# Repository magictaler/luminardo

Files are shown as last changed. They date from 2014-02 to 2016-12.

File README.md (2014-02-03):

Luminardo
=========

An open source Arduino-like hardware project with modular architecture and compact dimentions with the following features in base configuration:

- 8 digits by 6 segments VFD display;
- IR receiver;
- Photocell for brightness adjustmens;
- Buzzer;
- RGB LED with individual colors controlled independently by PWM;
- Single (either 5VDC or 12VDC) power supply;
- Lithium battery bucked up RTC;
- 1 Wire temperature sensor (with capability to connect more than one);
- USB Host functionality*;
- USB-to-Serial interface for progamming and debugging;
- 128 kb of program memory, 3.3V internal supply and logic levels;
- 5V tolerant ISP header; 
- I2C, secondary UART, secondary SPI for future extentions;
- PIR sensor;
- Integration with Arduino IDE;
- Firmware is tightly integrared with an awesome "Revision 2.0 of USB Host Library for Arduino" (thank you guys!)

for more information please visit http://luminardo.net and http://magictale.com

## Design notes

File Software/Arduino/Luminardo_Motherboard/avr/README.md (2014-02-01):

# Luminardo 1284P: Platform files for Luminardo on ATmega1284P

## What is it?

Everything you need to run Luminardo on ATmega1284P.

## Current state

Alpha revision

## Installation

1. Download the [ZIP File](***TBD***)
2. Unzip it a folder called 'hardware'of your sketches directory, e.g. /Users/magictaler/Source/Arduino/hardware/luminardo-1284p
3. Restart the IDE
4. Select Tools > Board > Luminardo 1284p 10MHz
5. To burn the bootloader, follow the Arduino [Bootloader](http://arduino.cc/en/Hacking/Bootloader) instructions.

## Requirements

* Works only on Arduino >= 1.0
* Can be burned using [USBtinyISP](http://www.ladyada.net/make/usbtinyisp/).  That programmer reports errors when flashing to chips with >64k flash size hovewer still does the job.

## See also

http://atmega.magictale.com/Luminardo

## Supported Boards

* 'Luminardo 1284p 10MHz'.  The main and the only board for now.

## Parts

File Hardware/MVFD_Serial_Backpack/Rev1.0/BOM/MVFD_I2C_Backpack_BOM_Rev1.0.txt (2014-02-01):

Partlist exported from D:/Projects/Electronics/InProgress/MVFD_I2C_Backpack/Eagle/Rev1.0/MVFD_I2C_Backpack.sch at 9/28/2013 10:06:53 PM

Qty Value          Device                   Package                   Parts                                      Description                                                             DIGIKEY           LICENSE OPT1 OPT2 OPT3 OPT4   P1     P2  P3   P4  P5 P6 P7 P8 P9  P10 P11 P12   P13  P14  PCBREV              PROJECT              URL                        
3   0.1uF          CAPACITOR_NPOL-1206      C1206                     C1, C2, C3                                 Non-Polarized capacitor in various packages                             445-14296-1-ND                                                                                                                                                                  
1   100K           RESISTOR-1206            R1206                     R4                                                                                                                 RHM100KYCT-ND                                                                                                                                                                   
1   10K            RESISTOR-1206            R1206                     R1                                                                                                                 RHM10KZCT-ND                                                                                                                                                                    
1   10uF           CAPACITOR_NPOL-1206      C1206                     C6                                         Non-Polarized capacitor in various packages                             399-1299-1-ND                                                                                                                                                                   
1   16MHz          OSC-XTAL-HC-49U-SMD      HC-49U                    Y1                                                                                                                 887-1059-1-ND                                                                                                                                                                   
2   1K5            RESISTOR-1206            R1206                     R2, R3                                                                                                             RHM1.50KYCT-ND                                                                                                                                                                  
2   22pF           CAPACITOR_NPOL-1206      C1206                     C4, C5                                     Non-Polarized capacitor in various packages                             399-8165-1-ND                                                                                                                                                                   
1   ATMEGA328P     ATMEGA168                TQFP32-08                 U1                                                                                                                 ATMEGA328P-AU-ND                                                                                                                                                                
1   CTRL           CONN_HEADER_2X07F_MIRR   CONN_HEADER_2X07_F_MIRR   P4                                         JUMPER                                                                  S7075-ND                                                                                                                                                                        
1   DMG2307L-7     TRANSISTOR_FET_TSM2301CX SOT-23                    Q1                                         20V P-Channel Enhancement Mode MOSFET                                   DMG2307L-7DICT-ND                                                                                                                                                               
4   FIDUCIAL       FIDUCIAL                 FIDUCIAL_1MM              FIDUTIAL1, FIDUTIAL2, FIDUTIAL3, FIDUTIAL4 For use by pick and place machines to calibrate the vision/machine, 1mm                                                                                                                                                                                 
1   HDR_7P2R_DESCR HDR_7P2R_DESCR           HDR_7P2R_DESCR            U$2                                                                                                                                                                IR_REC +5V SPKR GND DO B  DI G  CLK R   CS  L_SNR VSEG SHDN                                                                     
1   I2C            CONN_HEADER_1X04RA_POLAR CONN_HEADER_1X04_RA_POLAR P1                                         2.54 1x4 Header                                                         732-2701-ND                                                                                                                                                                     
1   ISP            CONN_HEADER_2X03         CONN_HEADER_2X03          P3                                         2.54 2x3 Header                                                         3M9459-ND                                                                                                                                                                       
1   JUMP_4X2_DESCR JUMP_4X2_DESCR           JUMP_4X2_DESCR            U$4                                                                                                                                          A1   A2   A3   SER_EN                                                                                                                                 
2   MOUNT-HOLE3.3  MOUNT-HOLE3.3            3,3                       H1, H2                                     MOUNTING HOLE with drill center marker                                                                                                                                                                                                                  
1   MT_LOGO        MT_LOGO                  MT_LOGO                   U$1                                                                                                                                  CC3.0                                                                                     REV 1.0, 2013.09.28 MVFD Serial Backpack http://atmega.magictale.com
1   OPT SEL        CONN_HEADER_2X04         CONN_HEADER_2X04          JP1                                        2.54 2x4 Header                                                         609-3226-ND                                                                                                                                                                     
1   SERIAL         CONN_HEADER_1X04RA_POLAR CONN_HEADER_1X04_RA_POLAR P2                                         2.54 1x4 Header                                                         732-2701-ND

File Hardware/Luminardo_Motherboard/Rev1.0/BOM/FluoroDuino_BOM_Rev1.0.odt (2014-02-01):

FluoroDuino Rev.1.0

Bill Of Materials

Picture | Position | DIGIKEY Part Number | Value | Unit price, USD | Qty | Extended price, USD
| B1 | BS-3-ND | HOLDER COINCELL 2032 RETAINR ARM | 0.79 | 1 | 0.79
| C1, C2, C4, C6, C11, C12, C13, C14, C15, C16, C21 | 445-14296-1-ND | CAP CER 0.1UF 50V 20% X5R 0612 | 0.38 | 11 | 4.16
| C10, C22 | 276-3044-1-ND | CAP CER 10UF 10V 20% X5R 1206 | 0.23 | 2 | 0.46
| C17 | 399-1234-1-ND | CAP CER 10000PF 50V 10% X7R 1206 | 0.16 | 1 | 0.16
| C18 | P16502CT-ND | CAP ALUM 56UF 20V 20% SMD | 1.28 | 1 | 1.28
| C20 | 587-1434-1-ND | CAP CER 1UF 25V 10% X5R 1206 | 0.48 | 1 | 0.48
| C3, C5, C8, C9 | 1276-1844-1-ND | CAP CER 18PF 50V 5% NP0 1206 | 0.16 | 4 | 0.64
| C7, C19 | 445-14685-1-ND | CAP CER 4.7UF 25V 20% X5R 1206 | 0.35 | 2 | 0.7
| D1, D2 | 568-6504-1-ND | DIODE SCHOTTKY 20V 1A SOD123W | 0.48 | 2 | 0.96
| F1 | 507-1798-1-ND | PTC RESTTBLE 0.25A 16V CHIP 1206 | 0.12 | 1 | 0.12
| J1 | CP-012A-ND | CONN PWR JCK 2.0 X 6.6MM | 1.4 | 1 | 1.4
| L1 | 445-6533-1-ND | INDUCTOR POWER 22UH 1.7A SMD | 0.52 | 1 | 0.52
| LD1, LD2 | 160-1737-1-ND | LED WHITE YELLOW 260MCD 1206 | 0.58 | 1 | 1.16
| P1 | 1175-1265-ND | USB 2.0 A/FEMALE DIP 180 DEG | 0.83 | 1 | 0.83
| P11 | SAM1034-01-ND | CONN HEADER 2POS .100" DUAL TIN | 0.85 | 1 | 0.85
| P2, P4 | SAM1034-02-ND | CONN HEADER 4POS .100" DUAL TIN | 1.86 | 1 | 1.86
| P3, P10 | SAM1034-02-ND | CONN HEADER 4POS .100" DUAL TIN | 1.86 | 1 | 1.86
| P5 | 732-2735-ND | CONN MINI USB 5PIN VERT T/H | 3.18 | 1 | 3.18
| P6, P9 | 609-3210-ND | CONN HEADER 6POS .100 STR 15AU | 0.58 | 1 | 0.58
| P7 | 609-3235-ND | CONN HEADER 8POS .100 STR 15AU | 0.32 | 1 | 0.32
| P8 | OR1103-ND | JUMPER PLUG 14POS DOUBLE ROW | 0.76 | 1 | 0.76
| Q1 | DMG2307L-7DICT-ND | MOSFET P-CH 30V 2.5A SOT-23 | 0.44 | 1 | 0.44
| R1, R2, R3, R8, R15 | RMCF1206JT10K0CT-ND | RES 10K OHM 1/4W 5% 1206 | 0.05 | 5 | 0.25
| R10, R11, R12, R13 | RMCF1206JT1K00CT-ND | RES 1K OHM 1/4W 5% 1206 | 0.05 | 4 | 0.2
| R14 | RMCF1206JT100KCT-ND | RES 100K OHM 1/4W 5% 1206 | 0.05 | 1 | 0.05
| R4, R5 | RMCF1206JT33R0 | RES 33 OHM 1/4W 5% 1206 | 0.05 | 2 | 0.1
| R6 | RMCF1206JT4K70CT-ND | RES 4.7K OHM 1/4W 5% 1206 | 0.05 | 1 | 0.05
| R7, R9 | RNCP1206FTD1K50CT-ND | RES 1.5K OHM 1/2W 1% 1206 | 0.09 | 2 | 0.18
| U1 | DS18B20+T&RCT-ND | IC THERM MICROLAN PROG-RES TO92 | 4.6 | 1 | 4.6
| U2 | MAX3421EEHJ+-ND | IC USB PERIPH/HOST CNTRL 32TQFP | 13.21 | 1 | 13.21
| U3 | ATMEGA1284P-AURCT-ND | IC MCU 8BIT 128KB FLASH 44TQFP | 8.43 | 1 | 8.43
| U4 | NCP380HSN05AAT1GOSCT-ND | IC CURRENT LIMIT SWITCH 5-TSOP | 0.74 | 1 | 0.74
| U5 | 296-4530-1-ND | IC BUS BUFFER TRI-ST QD 14SOICN | 0.49 | 1 | 0.49
| U6 | 768-1007-1-ND | IC USB FS SERIAL UART 28-SSOP | 4.5 | 1 | 4.5
| U7 | DS1338U-33+T&RCT-ND | IC RTC 56BYTE NV RAM 3.3V 8-USOP | 3.28 | 1 | 3.28
| U8 | LM22675MR-5.0/NOPB-ND | LM22675MR-5.0/NOPB-ND | 3.91 | 1 | 3.91
| U9 | 497-1241-1-ND | IC REG LDO 3.3V 0.95A SOT223 | 0.54 | 1 | 0.54
| Y1 | 535-9833-1-ND | CRYSTAL 10MHZ 18PF SMD | 1.31 | 1 | 1.31
| Y2 | 535-9836-1-ND | CRYSTAL 12MHZ 18PF SMD | 1.31 | 1 | 1.31
| Y3 | 300-8816-1-ND | CRYSTAL 32.768KHZ 12.5PF SMD | 1.43 | 1 | 1.43
| ZD1 | 1N5819HW-FDICT-ND | DIODE SCHOTTKY 40V 1A SOD123 | 0.52 | 1 | 0.52
Total | | | | | | 68.61

Rev.1.0 http://magictale.com 4 Of 6

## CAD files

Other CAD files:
Hardware/MVFD_Serial_Backpack/Rev1.0/Sketchup/MVFD_16S8D_Serial_Backpack_3D_Rev1.0.skp

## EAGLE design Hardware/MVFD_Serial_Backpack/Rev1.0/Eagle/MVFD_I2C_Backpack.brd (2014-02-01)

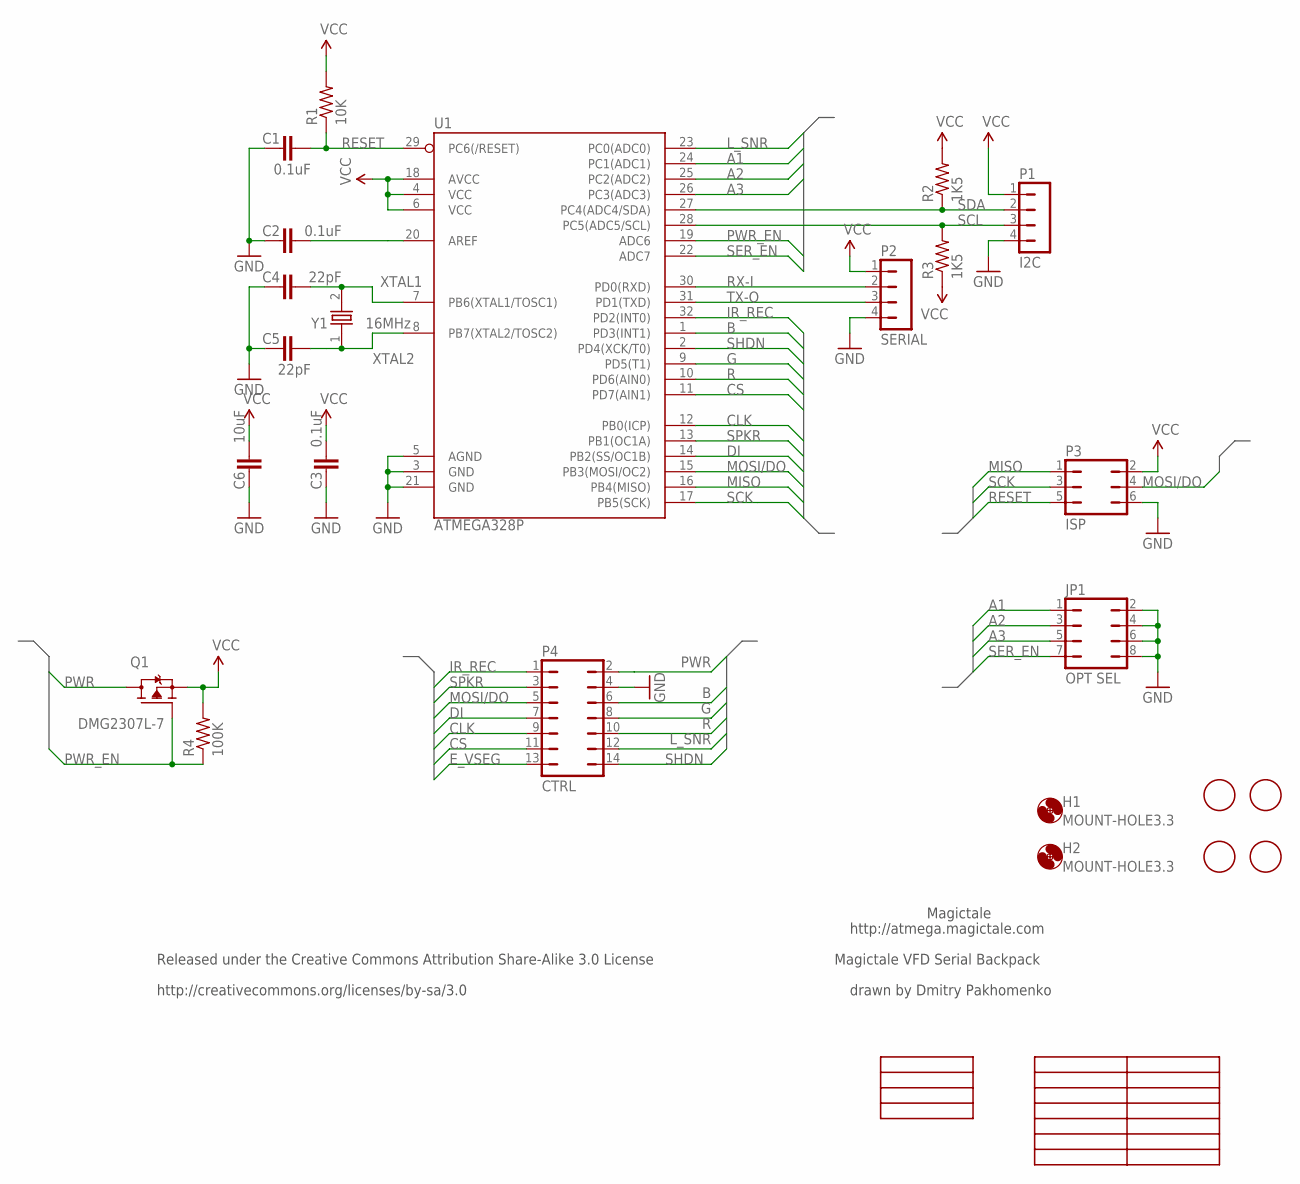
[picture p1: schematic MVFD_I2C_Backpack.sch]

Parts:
C1, C2, C3: 0.1uF; C1206; DIGIKEY 445-14296-1-ND
C4, C5: 22pF; C1206; DIGIKEY 399-8165-1-ND
C6: 10uF; C1206; DIGIKEY 399-1299-1-ND
FIDUTIAL1, FIDUTIAL2, FIDUTIAL3, FIDUTIAL4: FIDUCIAL; FIDUCIAL_1MM
H1, H2: MOUNT-HOLE3.3; 3,3
JP1: OPT SEL; CONN_HEADER_2X04; DIGIKEY 609-3226-ND
P1: I2C; CONN_HEADER_1X04_RA_POLAR; DIGIKEY 732-2701-ND
P2: SERIAL; CONN_HEADER_1X04_RA_POLAR; DIGIKEY 732-2701-ND
P3: ISP; CONN_HEADER_2X03; DIGIKEY 3M9459-ND
P4: CTRL; CONN_HEADER_2X07_F_MIRR; DIGIKEY S7075-ND
Q1: DMG2307L-7; SOT-23; DIGIKEY DMG2307L-7DICT-ND
R1: 10K; R1206; DIGIKEY RHM10KZCT-ND
R2, R3: 1K5; R1206; DIGIKEY RHM1.50KYCT-ND
R4: 100K; R1206; DIGIKEY RHM100KYCT-ND
U1: ATMEGA328P; TQFP32-08; DIGIKEY ATMEGA328P-AU-ND
U$1: MT_LOGO
U$2: HDR_7P2R_DESCR
U$4: JUMP_4X2_DESCR
Y1: 16MHz; HC-49U; DIGIKEY 887-1059-1-ND

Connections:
A1: JP1.1, U1.24 (PC1(ADC1))
A2: JP1.3, U1.25 (PC2(ADC2))
A3: JP1.5, U1.26 (PC3(ADC3))
AREF: C2.2, U1.20 (AREF)
B: P4.6, U1.1 (PD3(INT1))
CLK: P4.9, U1.12 (PB0(ICP))
CS: P4.11, U1.11 (PD7(AIN1))
DI: P4.7, U1.14 (PB2(SS/OC1B))
E_VSEG: P4.13
G: P4.8, U1.9 (PD5(T1))
GND: C1.1, C2.1, C3.1, C4.1, C5.1, C6.1, JP1.2, JP1.4, JP1.6, JP1.8, P1.4, P2.4, P3.6, P4.4, U1.3 (GND), U1.5 (AGND), U1.21 (GND)
IR_REC: P4.1, U1.32 (PD2(INT0))
L_SNR: P4.12, U1.23 (PC0(ADC0))
MISO: P3.1, U1.16 (PB4(MISO))
MOSI/DO: P3.4, P4.5, U1.15 (PB3(MOSI/OC2))
PWR: P4.2, Q1.3 (D)
PWR_EN: Q1.1 (G), R4.1, U1.19 (ADC6)
R: P4.10, U1.10 (PD6(AIN0))
RESET: C1.2, P3.5, R1.1, U1.29 (PC6(/RESET))
RX-I: P2.2, U1.30 (PD0(RXD))
SCK: P3.3, U1.17 (PB5(SCK))
SCL: P1.3, R3.2, U1.28 (PC5(ADC5/SCL))
SDA: P1.2, R2.1, U1.27 (PC4(ADC4/SDA))
SER_EN: JP1.7, U1.22 (ADC7)
SHDN: P4.14, U1.2 (PD4(XCK/T0))
SPKR: P4.3, U1.13 (PB1(OC1A))
TX-O: P2.3, U1.31 (PD1(TXD))
VCC: C3.2, C6.2, P1.1, P2.1, P3.2, Q1.2 (S), R1.2, R2.2, R3.1, R4.2, U1.4 (VCC), U1.6 (VCC), U1.18 (AVCC)
XTAL1: C4.2, U1.7 (PB6(XTAL1/TOSC1)), Y1.2
XTAL2: C5.2, U1.8 (PB7(XTAL2/TOSC2)), Y1.1

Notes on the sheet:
Magictale
http://atmega.magictale.com
Magictale VFD Serial Backpack
drawn by Dmitry Pakhomenko
Released under the Creative Commons Attribution Share-Alike 3.0 License
http://creativecommons.org/licenses/by-sa/3.0

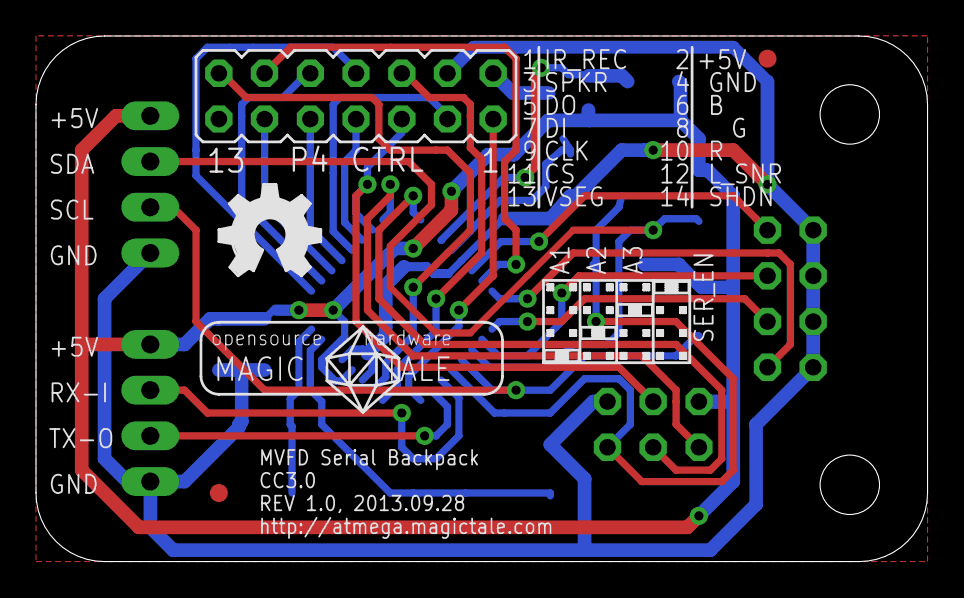
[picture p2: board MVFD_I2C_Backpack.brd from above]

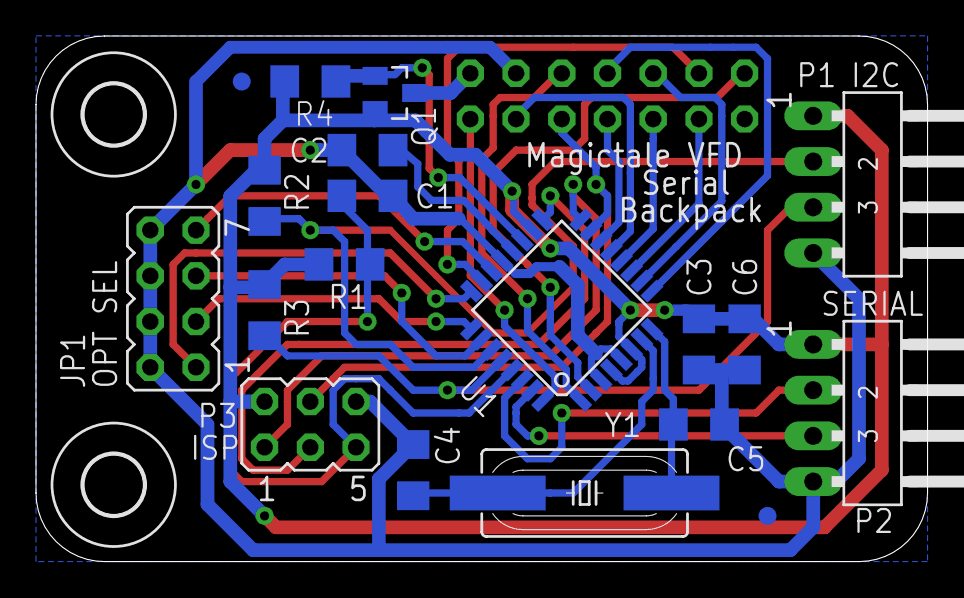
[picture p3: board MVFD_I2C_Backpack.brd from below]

Board: 2 copper layers, 49.5 x 29.2 mm, 28 parts (22 on the bottom side), 29 nets.

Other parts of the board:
U$3: LOGO_OSHW_FILLX200_NOTEXT

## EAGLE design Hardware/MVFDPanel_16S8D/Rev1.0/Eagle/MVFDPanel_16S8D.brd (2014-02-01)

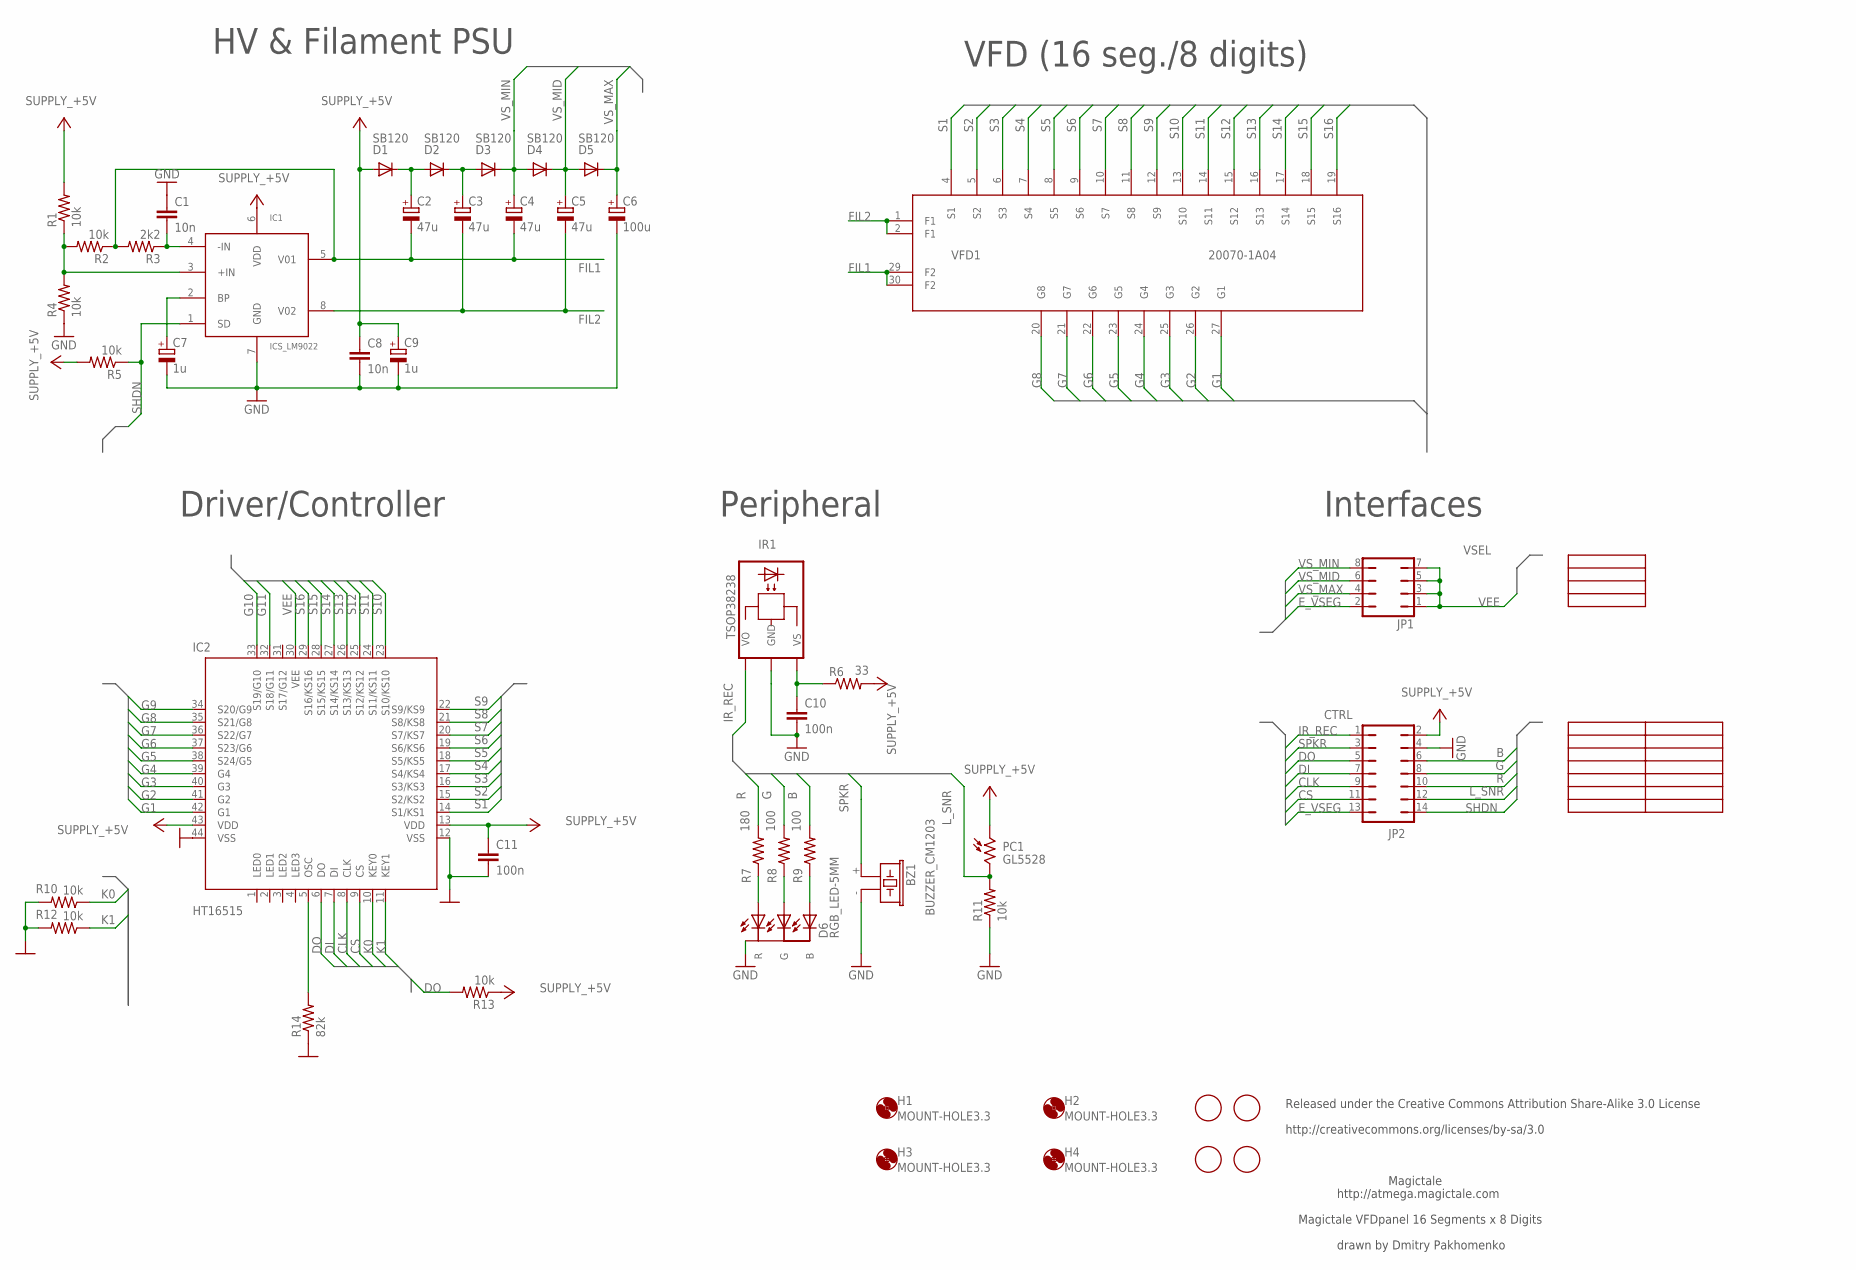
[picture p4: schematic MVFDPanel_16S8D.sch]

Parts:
BZ1: BUZZER_CM1203; CEM-1203
C1, C8: 10n; C025-025X050; DIGIKEY 399-4150-ND
C2, C3, C4, C5: 47u; E2,5-7; DIGIKEY P11232-ND
C6: 100u; E3,5-8; DIGIKEY P10294-ND
C7, C9: 1u; E2-5; DIGIKEY P13468-ND
C10, C11: 100n; C050-025X075; DIGIKEY 490-3859-ND
D1, D2, D3, D4, D5: SB120; DO41-10; DIGIKEY MBR160-ND
D6: RGB_LED-5MM
FIDUTIAL1, FIDUTIAL2, FIDUTIAL3, FIDUTIAL4: FIDUCIAL; FIDUCIAL_1MM
H1, H2, H3, H4: MOUNT-HOLE3.3; 3,3
IC1: ICS_LM9022; ICS_SOP08; DIGIKEY LM9022M-ND
IC2: HT16515; LQFP44-10X10
IR1: TSOP38238; DIGIKEY 751-1227-ND
JP1: VSEL; JP4Q
JP2: CTRL; JP7Q
PC1: GL5528
R1, R2, R4, R5, R10, R11, R12, R13: 10k; 0207/2V; DIGIKEY 10KQBK-ND
R3: 2k2; 0207/2V; DIGIKEY 2.2KQTR-ND
R6: 33; 0207/2V; DIGIKEY 33QBK-ND
R7: 180; 0207/2V; DIGIKEY 180QBK-ND
R8, R9: 100; 0207/2V; DIGIKEY 100QBK-ND
R14: 82k; 0207/2V; DIGIKEY 82KQBK-ND
U$1: MT_LOGO
U$2: HDR_7P2R_DESCR
U$3: JUMP_4X2_DESCR
VFD1: 20070-1A04

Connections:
+5V: C8.1, C9.+, C11.1, D1.A, IC1.6 (VDD), IC2.13 (VDD), IC2.43 (VDD), JP2.2, PC1.1, R1.2, R5.2, R6.2, R13.1
B: JP2.6, R9.2
CLK: IC2.8 (CLK), JP2.9
CS: IC2.9 (CS), JP2.11
DI: IC2.7 (DI), JP2.7
DO: IC2.6 (DO), JP2.5, R13.2
E_VSEG: JP1.2, JP2.13
FIL1: C2.-, C4.-, IC1.5 (V01), R2.1, R3.2, VFD1.29 (F2), VFD1.30 (F2)
FIL2: C3.-, C5.-, IC1.8 (V02), VFD1.1 (F1), VFD1.2 (F1)
G: JP2.8, R8.2
G1: IC2.42 (G1), VFD1.27 (G1)
G2: IC2.41 (G2), VFD1.26 (G2)
G3: IC2.40 (G3), VFD1.25 (G3)
G4: IC2.39 (G4), VFD1.24 (G4)
G5: IC2.38 (S24/G5), VFD1.23 (G5)
G6: IC2.37 (S23/G6), VFD1.22 (G6)
G7: IC2.36 (S22/G7), VFD1.21 (G7)
G8: IC2.35 (S21/G8), VFD1.20 (G8)
G9: IC2.34 (S20/G9)
G10: IC2.33 (S19/G10)
G11: IC2.32 (S18/G11)
GND: BZ1.- (2), C1.1, C6.-, C7.-, C8.2, C9.-, C10.2, C11.2, D6.CC, IC1.7 (GND), IC2.12 (VSS), IC2.44 (VSS), IR1.GND, JP2.4, R4.1, R10.2, R11.1, R12.2, R14.1
IR_REC: IR1.VO, JP2.1
K0: IC2.10 (KEY0), R10.1
K1: IC2.11 (KEY1), R12.1
L_SNR: JP2.12, PC1.2, R11.2
unnamed: C10.1, IR1.VS, R6.1
unnamed: IC2.5 (OSC), R14.2
unnamed: C7.+, IC1.2 (BP)
unnamed: D6.R, R7.1
unnamed: D6.G, R8.1
unnamed: D6.B, R9.1
unnamed: IC1.3 (+IN), R1.1, R2.2, R4.2
unnamed: C2.+, D1.C, D2.A
unnamed: C3.+, D2.C, D3.A
PORTD6: C1.2, IC1.4 (-IN), R3.1
R: JP2.10, R7.2
S1: IC2.14 (S1/KS1), VFD1.4 (S1)
S2: IC2.15 (S2/KS2), VFD1.5 (S2)
S3: IC2.16 (S3/KS3), VFD1.6 (S3)
S4: IC2.17 (S4/KS4), VFD1.7 (S4)
S5: IC2.18 (S5/KS5), VFD1.8 (S5)
S6: IC2.19 (S6/KS6), VFD1.9 (S6)
S7: IC2.20 (S7/KS7), VFD1.10 (S7)
S8: IC2.21 (S8/KS8), VFD1.11 (S8)
S9: IC2.22 (S9/KS9), VFD1.12 (S9)
S10: IC2.23 (S10/KS10), VFD1.13 (S10)
S11: IC2.24 (S11/KS11), VFD1.14 (S11)
S12: IC2.25 (S12/KS12), VFD1.15 (S12)
S13: IC2.26 (S13/KS13), VFD1.16 (S13)
S14: IC2.27 (S14/KS14), VFD1.17 (S14)
S15: IC2.28 (S15/KS15), VFD1.18 (S15)
S16: IC2.29 (S16/KS16), VFD1.19 (S16)
SHDN: IC1.1 (SD), JP2.14, R5.1
SPKR: BZ1.+ (1), JP2.3
VEE: IC2.30 (VEE), JP1.1, JP1.3, JP1.5, JP1.7
VS_MAX: C6.+, D5.C, JP1.4
VS_MID: C5.+, D4.C, D5.A, JP1.6
VS_MIN: C4.+, D3.C, D4.A, JP1.8

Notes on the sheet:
HV & Filament PSU
Driver/Controller
VFD (16 seg./8 digits)
Peripheral
Interfaces
Magictale
http://atmega.magictale.com
Magictale VFDpanel 16 Segments x 8 Digits
drawn by Dmitry Pakhomenko
Released under the Creative Commons Attribution Share-Alike 3.0 License
http://creativecommons.org/licenses/by-sa/3.0

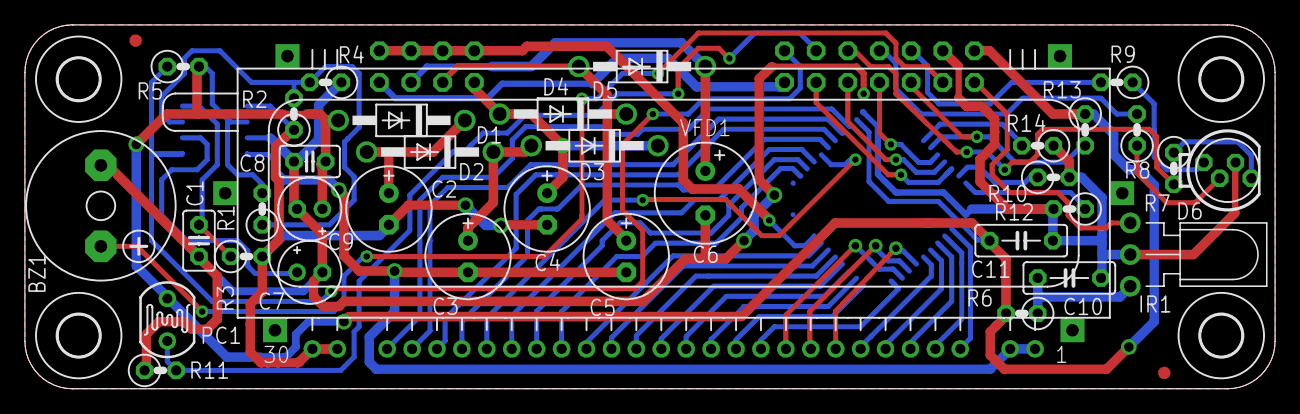
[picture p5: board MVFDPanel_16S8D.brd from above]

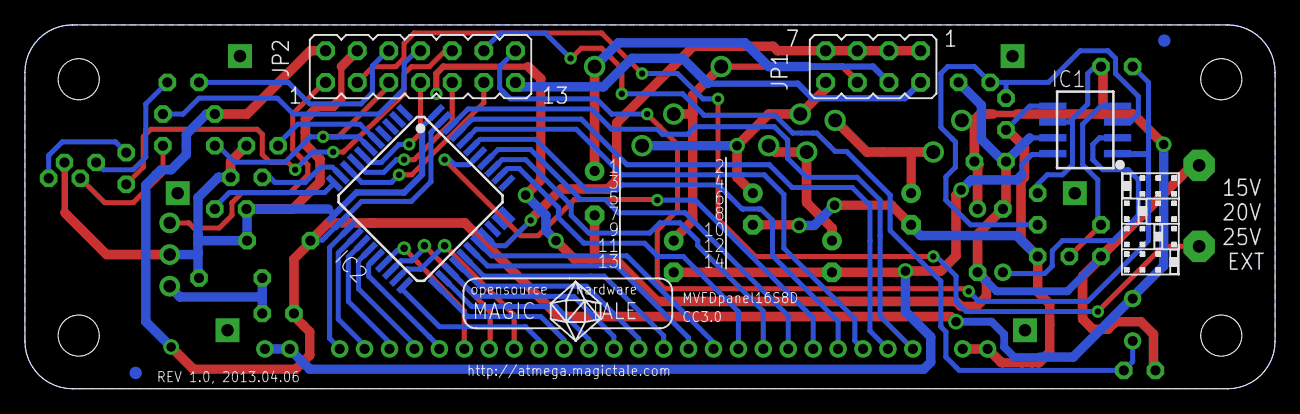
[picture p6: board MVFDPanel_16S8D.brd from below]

Board: 2 copper layers, 100.3 x 29.2 mm, 50 parts (9 on the bottom side), 56 nets.

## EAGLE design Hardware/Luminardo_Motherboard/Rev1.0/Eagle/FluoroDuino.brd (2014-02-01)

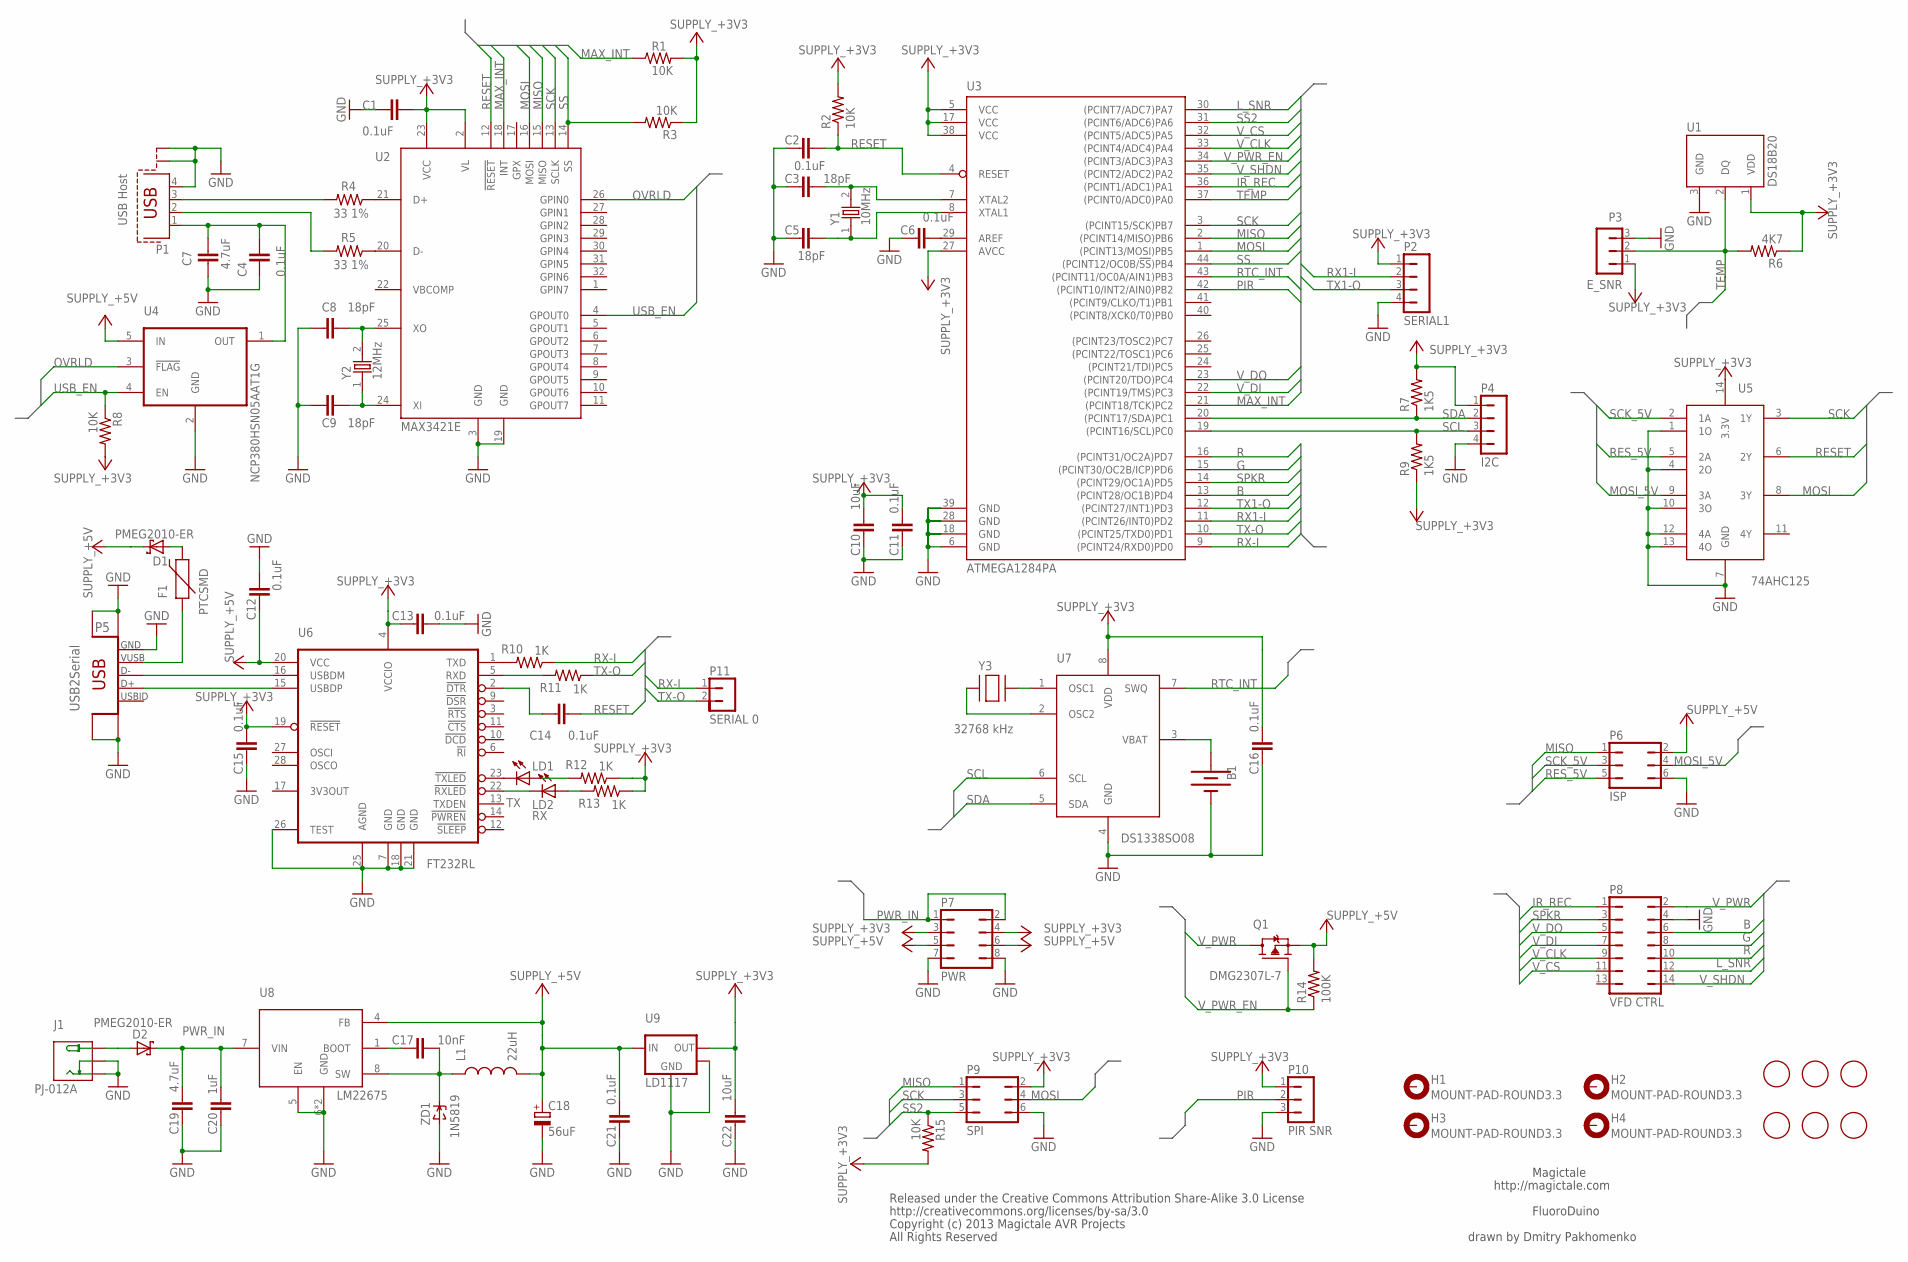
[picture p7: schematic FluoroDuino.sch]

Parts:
B1: BATTERY20PTH; BATTCOM_20MM_PTH; DIGIKEY BS-3-ND
C1, C2, C4, C6, C11, C12, C13, C14, C15, C16, C21: 0.1uF; C1206; DIGIKEY 445-14296-1-ND
C3, C5, C8, C9: 18pF; C1206; DIGIKEY 1276-1844-1-ND
C7, C19: 4.7uF; C1206; DIGIKEY 445-14685-1-ND
C10: 10uF; C1206; DIGIKEY 276-3044-1-ND
C17: 10nF; C1206; DIGIKEY 399-1234-1-ND
C18: 56uF; PANASONIC_C; DIGIKEY P16502CT-ND
C20: 1uF; C1206; DIGIKEY 587-1434-1-ND
C22: 10uF; C1206; DIGIKEY 1276-3044-1-ND
D1, D2: PMEG2010-ER; SOD123; DIGIKEY 568-6504-1-ND
F1: PTCSMD; PTC-1206; DIGIKEY 507-1798-1-ND
FIDUTIAL1, FIDUTIAL2, FIDUTIAL3, FIDUTIAL4, FIDUTIAL5, FIDUTIAL6: FIDUCIAL; FIDUCIAL_1MM
H1, H2, H3, H4: MOUNT-PAD-ROUND3.3; 3,3-PAD
J1: PJ-012A; DIGIKEY CP-012A-ND
L1: 22uH; VLC6045; DIGIKEY 445-6533-1-ND
LD1: TX; CHIPLED_1206; DIGIKEY 160-1737-1-ND
LD2: RX; CHIPLED_1206; DIGIKEY 160-1737-1-ND
P1: USB Host; USB-A-VER
P2: SERIAL1; CONN_HEADER_1X04; DIGIKEY SAM1034-02-ND
P3: E_SNR; CONN_HEADER_1X03; DIGIKEY SAM1034-02-ND
P4: I2C; CONN_HEADER_1X04; DIGIKEY SAM1034-02-ND
P5: USB2Serial; CONN_USB_MINI_RA; DIGIKEY 732-2735-ND
P6: ISP; CONN_HEADER_2X03; DIGIKEY 609-3210-ND
P7: PWR; CONN_HEADER_2X04; DIGIKEY 609-3235-ND
P8: VFD CTRL; CONN_HEADER_2X07_F_MIRR; DIGIKEY OR1103-ND
P9: SPI; CONN_HEADER_2X03; DIGIKEY 609-3210-ND
P10: PIR SNR; CONN_HEADER_1X03; DIGIKEY SAM1034-02-ND
P11: SERIAL 0; CONN_HEADER_1X02; DIGIKEY SAM1034-01-ND
Q1: DMG2307L-7; SOT-23; DIGIKEY DMG2307L-7DICT-ND
R1, R2, R3, R8, R15: 10K; R1206; DIGIKEY RMCF1206JT10K0CT-ND
R4, R5: 33 1%; R1206; DIGIKEY RMCF1206JT33R0
R6: 4K7; R1206; DIGIKEY RMCF1206JT4K70CT-ND
R7, R9: 1K5; R1206; DIGIKEY RNCP1206FTD1K50CT-ND
R10, R11, R12, R13: 1K; R1206; DIGIKEY RMCF1206JT1K00CT-ND
R14: 100K; R1206; DIGIKEY RMCF1206JT100KCT-ND
U1: DS18B20; TO-92-AMMO; DIGIKEY DS18B20+T&RCT-ND
U2: MAX3421E; TQFP32-08; DIGIKEY MAX3421EEHJ+-ND
U3: ATMEGA1284PA; TQFP44; DIGIKEY ATMEGA1284P-AURCT-ND
U4: NCP380HSN05AAT1G; SOT23-5; DIGIKEY NCP380HSN05AAT1GOSCT-ND
U5: 74AHC125; SO014; DIGIKEY 296-4530-1-ND
U6: FT232RL; SSOP-28; DIGIKEY 768-1007-1-ND
U7: DS1338SO08; SO08; DIGIKEY DS1338U-33+T&RCT-ND
U8: LM22675; SO08_POWER_PAD; DIGIKEY LM22675MR-5.0/NOPB-ND
U9: LD1117; SOT223; DIGIKEY 497-1241-1-ND
U$: MT_LOGOCOMPACT; MT_LOGO_COMPACT
Y1: 10MHz; XTAL_4X6; DIGIKEY 535-9833-1-ND
Y2: 12MHz; XTAL_4X6; DIGIKEY 535-9836-1-ND
Y3: 32768 kHz; XTAL3215; DIGIKEY 300-8816-1-ND
ZD1: 1N5819; SOD123; DIGIKEY 1N5819HW-FDICT-ND

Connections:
+3V3: C1.1, C10.2, C11.2, C13.1, C15.2, C16.2, C22.2, P2.1, P3.1, P4.1, P7.3, P7.4, P9.2, P10.1, R1.2, R2.2, R3.1, R6.1, R7.2, R8.2, R9.1, R12.1, R13.1, R15.2, U1.1 (VDD), U2.2 (VL), U2.23 (VCC), U3.5 (VCC), U3.17 (VCC), U3.27 (AVCC), U3.38 (VCC), U5.14 (3.3V), U6.4 (VCCIO), U6.19 (!RESET), U7.8 (VDD), U9.2 (OUT)
+5V: C12.1, C18.+, C21.2, D1.C, L1.2, P6.2, P7.5, P7.6, Q1.2 (S), R14.2, U4.5 (IN), U6.20 (VCC), U8.4 (FB), U9.3 (IN)
B: P8.6, U3.13 ((PCINT28/OC1B)PD4)
G: P8.8, U3.15 ((PCINT30/OC2B/ICP)PD6)
GND: B1.2 (-), C1.2, C2.1, C3.1, C4.2, C5.1, C6.1, C7.1, C8.1, C9.1, C10.1, C11.1, C12.2, C13.2, C15.1, C16.1, C18.-, C19.1, C20.1, C21.1, C22.1, J1.2, J1.3, P1.4, P1.S1, P1.S2, P2.4, P3.3, P4.4, P5.5 (GND), P5.S1 (BODY), P5.S2 (BODY), P5.S3 (BODY), P5.S4 (BODY), P6.6, P7.7, P7.8, P8.4, P9.6, P10.3, U1.3 (GND), U2.3 (GND), U2.19 (GND), U3.6 (GND), U3.18 (GND), U3.28 (GND), U3.39 (GND), U4.2 (GND), U5.1 (1O), U5.4 (2O), U5.7 (GND), U5.10 (3O), U5.12 (4A), U5.13 (4O), U6.7 (GND), U6.18 (GND), U6.21 (GND), U6.25 (AGND), U6.26 (TEST), U7.4 (GND), U8.5 (EN), U8.6 (GND), U8.BODY@1 (GND), U9.1 (GND), U9.4 (OUT), ZD1.A
IR_REC: P8.1, U3.36 ((PCINT1/ADC1)PA1)
L_SNR: P8.12, U3.30 ((PCINT7/ADC7)PA7)
MAX_INT: R1.1, U2.18 (INT), U3.21 ((PCINT18/TCK)PC2)
MISO: P6.1, P9.1, U2.15 (MISO), U3.2 ((PCINT14/MISO)PB6)
MOSI: P9.4, U2.16 (MOSI), U3.1 ((PCINT13/MOSI)PB5), U5.8 (3Y)
MOSI_5V: P6.4, U5.9 (3A)
unnamed: U7.1 (OSC1), Y3.P$2
unnamed: U7.2 (OSC2), Y3.P$1
unnamed: B1.1 (+), U7.3 (VBAT)
unnamed: P5.3 (D+), U6.15 (USBDP)
unnamed: P5.2 (D-), U6.16 (USBDM)
unnamed: D1.A, F1.2
unnamed: LD1.C, U6.23 (!TXLED)
unnamed: R11.2, U6.5 (RXD)
unnamed: R10.2, U6.1 (TXD)
unnamed: LD2.C, U6.22 (!RXLED)
unnamed: LD1.A, R12.2
unnamed: LD2.A, R13.2
unnamed: C14.2, U6.2 (!DTR)
unnamed: C9.2, U2.24 (XI), Y2.1
unnamed: C8.2, U2.25 (XO), Y2.2
unnamed: R4.1, U2.21 (D+)
unnamed: R5.1, U2.20 (D-)
unnamed: P1.3, R4.2
unnamed: P1.2, R5.2
unnamed: F1.1, P5.1 (VUSB)
unnamed: D2.A, J1.1
unnamed: C4.1, C7.2, P1.1, U4.1 (OUT)
unnamed: C17.1, U8.1 (BOOT)
unnamed: C6.2, U3.29 (AREF)
unnamed: C17.2, L1.1, U8.8 (SW), ZD1.C
OVRLD: U2.26 (GPIN0), U4.3 (!FLAG)
PIR: P10.2, U3.42 ((PCINT10/INT2/AIN0)PB2)
PWR_IN: C19.2, C20.2, D2.C, P7.1, P7.2, U8.7 (VIN)
R: P8.10, U3.16 ((PCINT31/OC2A)PD7)
RESET: C2.2, C14.1, R2.1, U2.12 (!RESET), U3.4 (RESET), U5.6 (2Y)
RES_5V: P6.5, U5.5 (2A)
RTC_INT: U3.43 ((PCINT11/OC0A/AIN1)PB3), U7.7 (SWQ)
RX1-I: P2.2, U3.11 ((PCINT26/INT0)PD2)
RX-I: P11.1, R10.1, U3.9 ((PCINT24/RXD0)PD0)
SCK: P9.3, U2.13 (SCLK), U3.3 ((PCINT15/SCK)PB7), U5.3 (1Y)
SCK_5V: P6.3, U5.2 (1A)
SCL: P4.3, R9.2, U3.19 ((PCINT16/SCL)PC0), U7.6 (SCL)
SDA: P4.2, R7.1, U3.20 ((PCINT17/SDA)PC1), U7.5 (SDA)
SPKR: P8.3, U3.14 ((PCINT29/OC1A)PD5)
SS: R3.2, U2.14 (SS), U3.44 ((PCINT12/OC0B/!SS!)PB4)
SS2: P9.5, R15.1, U3.31 ((PCINT6/ADC6)PA6)
TEMP: P3.2, R6.2, U1.2 (DQ), U3.37 ((PCINT0/ADC0)PA0)
TX1-O: P2.3, U3.12 ((PCINT27/INT1)PD3)
TX-O: P11.2, R11.1, U3.10 ((PCINT25/TXD0)PD1)
USB_EN: R8.1, U2.4 (GPOUT0), U4.4 (EN)
V_CLK: P8.9, U3.33 ((PCINT4/ADC4)PA4)
V_CS: P8.11, U3.32 ((PCINT5/ADC5)PA5)
V_DI: P8.7, U3.22 ((PCINT19/TMS)PC3)
V_DO: P8.5, U3.23 ((PCINT20/TDO)PC4)
V_PWR: P8.2, Q1.3 (D)
V_PWR_EN: Q1.1 (G), R14.1, U3.34 ((PCINT3/ADC3)PA3)
V_SHDN: P8.14, U3.35 ((PCINT2/ADC2)PA2)
XTAL1: C3.2, U3.7 (XTAL2), Y1.2
XTAL2: C5.2, U3.8 (XTAL1), Y1.1

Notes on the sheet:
Magictale
http://magictale.com
FluoroDuino
drawn by Dmitry Pakhomenko
Released under the Creative Commons Attribution Share-Alike 3.0 License
http://creativecommons.org/licenses/by-sa/3.0
Copyright (c) 2013 Magictale AVR Projects
All Rights Reserved

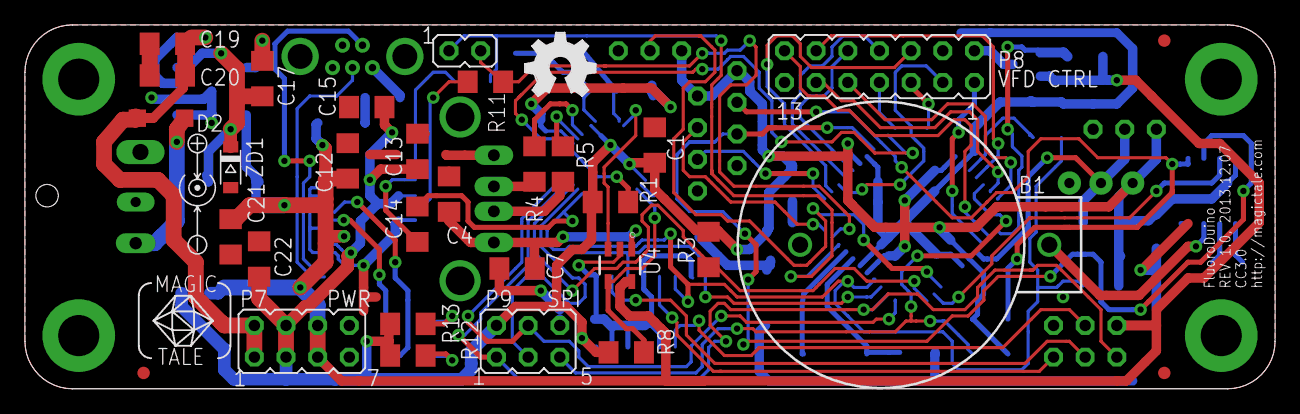
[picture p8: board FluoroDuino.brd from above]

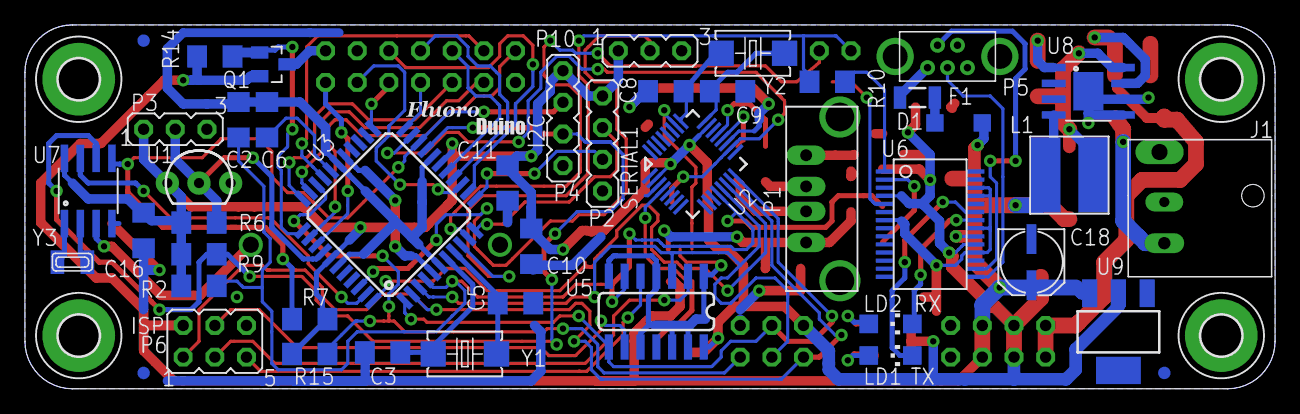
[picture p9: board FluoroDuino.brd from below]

Board: 2 copper layers, 100.3 x 29.2 mm, 83 parts (51 on the bottom side), 65 nets.

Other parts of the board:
U$1: FLUORODUINO_LOGO
U$3: LOGO_OSHW_FILLX200_NOTEXT

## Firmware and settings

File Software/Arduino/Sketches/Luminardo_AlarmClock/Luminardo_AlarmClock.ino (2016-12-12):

/*
 Luminardo Alarm Clock
 
 Copyright (c) 2014 Dmitry Pakhomenko.
 dmitryp@magictale.com
 http://magictale.com
 
 This example code is in the public domain.
 */

#define LUMINARDO_REV 2 

#include <Board.h>                       //Generic Luminardo definitions
#include <avr/pgmspace.h>
#include <avr/eeprom.h>
#include <DS1338.h>                      //RTC
#include <OneWire.h>                     //OneWire temperature sensor
#include <MVFDPanel_16S8D.h>             //VFD display
#include "AlarmClock.h"                  //AlarmClock specific definitions
#include "Messages.h"                    //Collection of string constants
#include "Utils.h"                       //Conversion utils and helpers
#include "ToneHelper.h"

void (*boot_loader_start)(void) = (void(*)(void))0x1F800; 

MVFD_16S8D vfd(VFD_CS_PIN, 
VFD_SCLK_PIN, VFD_DATAI_PIN, 
VFD_SHDN_PIN, VFD_PWR_EN_PIN);           //VFD display

OneWire ds(TEMP_SNSR_PIN);               //DS18B20 - a 1Wire temperature sensor from Dallas Semiconductor
volatile uint8_t pirEvent;  

uint8_t redValue;                        //current red value for front LED
uint8_t greenValue;                      //current green value for front LED
uint8_t blueValue;                       //current blue value for front LED
bool redValueUp;
bool greenValueUp;
bool blueValueUp;

uint8_t sysState;                        //current system state (mode)
uint8_t stateCntr;                       //counter for displaying current state (in sec) - when becomes
uint16_t mainLoopCntr;
//zero display state changes to the next one
uint8_t dsState;                         //temperature sensor state (to avoid explicit usage of delays)
RtcTimeType rtc;                         //current time
AlarmType alarm;                         //current alarm
float temperature;                       //current temperature
uint8_t actModeTimer;                    //seconds remaining before going to standby mode
EepromParamsType eepromParams EEMEM;     //RC keys allocations
uint8_t dsAddr[8];  //temperature sensor address
uint8_t dsData[12]; //temperature sensor data buffer
uint8_t alarmedSec;

void switchVFD(uint8_t state)
{
  cli();
  sysState = state;
  stateCntr = STD_DISP_TIME;
  vfd.standby(false);
  vfd.powerdown(false);
  vfd.reset();
  actModeTimer = SECONDS_IN_ACTIVE_MODE;
  sei();
}

// the setup routine runs once when you press reset:
void setup() {
  Serial.begin(57600);  

//  shortBeep();  

  //Initialize RTC
  rtc.year = -1;
  if (RTClock.init() == 0)
  {
    RTClock.setCtrlReg(1 << DS1338_CTRL_REG_SQWE);
    RTClock.setClockHalt();
    RTClock.resetClockHalt();
  }

  //Initialize temperature sensor variables
  temperature = FAILED_TEMPERATURE;
  dsState = dsIdle;

  //Initialize VFD panel
  vfd.initLED(VFD_R_PIN, VFD_G_PIN, VFD_B_PIN);
  vfd.initLightSensor(VFD_LIGHT_SNR_PIN);
  //vfd.initTone(VFD_SPRK_PIN);
  vfd.initIR_RC(VFD_IR_REC_PIN, VFD_SPRK_PIN);

  redValue = 0;
  greenValue = 127;
  blueValue = 0;
  
  vfd.setLED(redValue, greenValue, blueValue);

  pinMode(VFD_DATAO_PIN, INPUT);
  switchVFD(sysGreetings);

  serial_print_p(PRODUCT_NAME);
  serial_print_p(SPACE_CHAR);
  serial_print_p(FIRMWARE_REV);
  serial_print_p(SPACE_CHAR);
  serial_println_p(FIRMWARE_DATE);

  mainLoopCntr = 0;
  
  //Initialize PIR sensor  
  pinMode(PIR_PIN, INPUT);
  EICRA |= (1 << ISC21) | (1 << ISC20);
  EIMSK |= (1 << INT2);
  pirEvent = false;

  RestoreAlarm();

  vfd.spkrOn(10000);
}

void toStandBy()
{
  cli();
  sysState = sysStandby;
  vfd.setLED(0, 0, 0);
  vfd.standby(true);
  sei();
}

void pulseLED(uint8_t &ledVal, bool &ledValueUp)
{
  if (ledVal != 0)
  {
      if (ledValueUp)
      {
          if (ledVal >= 250)
          {
              ledVal -= 5;
              ledValueUp = false;
          } else ledVal += 5;
      }else
      {
          if (ledVal <= 6)
          {
              ledVal += 5;
              ledValueUp = true;
          } else ledVal -= 5;
      }
  }
}

void pulseLEDs()
{
   if (sysState == sysTimeDisp || sysState == sysDayOfWeekDisp || sysState == sysExtTempDisp || sysState == sysIntTempDisp || sysState == sysDateDisp)
   { 
      blueValue++;
      if (blueValue > 60)
      {
          blueValue = 0;  
      }
      if (blueValue < 30)
      {
         vfd.setLED(blueValue/1.17, blueValue/8.6, blueValue);
      }else
      {
         uint8_t newVal = (30 - (blueValue - 30));
         vfd.setLED(newVal/1.17, newVal/8.6, newVal);
      }
   }else if (sysState == sysSetHours || sysState == sysSetMinutes || sysState == sysResetSeconds || sysState == sysSetYear || sysState == sysSetMonth ||
       sysState == sysSetDay || sysState == sysSetDayOfWeek || sysState == sysSetAlarmHours || sysState == sysSetAlarmMinutes || sysState == sysSetAlarmState)
   {
       vfd.setLED(127, 127, 0);
   }else if (sysState == sysWaitForSetup || sysState == sysRCSetupLeft || sysState == sysRCSetupRight || sysState == sysRCSetupUp || sysState == sysRCSetupDown ||
       sysState == sysRCSetupSettings)
   {
       vfd.setLED(0, 255, 0);
   }else if (sysState == sysStandby)
   {
       ;
   }
}

uint8_t isCodeEqual(decode_results *results, uint32_t* addr)
{
  eeprom_busy_wait();
  uint16_t rcType = eeprom_read_word(&eepromParams.rcType);
  if (rcType != results->decode_type)
    return false;

  eeprom_busy_wait();
  uint32_t rcCmd = eeprom_read_dword(addr);
  return (rcCmd == results->value);
}

void printStoredRCComs()
{
  eeprom_busy_wait();
  uint16_t rcType = eeprom_read_word(&eepromParams.rcType);
  Serial.print(F("RCType")); 
  Serial.println(rcType, HEX); 

  eeprom_busy_wait();
  uint32_t rcCmd = eeprom_read_dword(&eepromParams.rcAction_Left_Code);
  Serial.print(F("rcAction_Left_Code")); 
  Serial.println(rcCmd, HEX); 

  eeprom_busy_wait();
  rcCmd = eeprom_read_dword(&eepromParams.rcAction_Right_Code);
  Serial.print(F("rcAction_Right_Code")); 
  Serial.println(rcCmd, HEX); 

  eeprom_busy_wait();
  rcCmd = eeprom_read_dword(&eepromParams.rcAction_Up_Code);
  Serial.print(F("rcAction_Up_Code")); 
  Serial.println(rcCmd, HEX); 

  eeprom_busy_wait();
  rcCmd = eeprom_read_dword(&eepromParams.rcAction_Down_Code);
  Serial.print(F("rcAction_Down_Code")); 
  Serial.println(rcCmd, HEX); 

  eeprom_busy_wait();
  rcCmd = eeprom_read_dword(&eepromParams.rcAction_Settings_Code);
  Serial.print(F("rcAction_Settings_Code")); 
  Serial.println(rcCmd, HEX); 
  
}

void updateRCCmdInFlash(decode_results *results, uint32_t* addr)
{
  eeprom_busy_wait();
  uint16_t rcType = eeprom_read_word(&eepromParams.rcType);
  if (rcType != results->decode_type)
  {
    eeprom_busy_wait();
    eeprom_write_word(&eepromParams.rcType, results->decode_type);
  }

  eeprom_busy_wait();
  uint32_t rcCmd = eeprom_read_dword(addr);
  if (rcCmd != results->value)
  {
    eeprom_busy_wait();
    eeprom_write_dword(addr, results->value);
  }

  printStoredRCComs();

  delay(RCCMD_UPDATE_DELAY);
}



void defaultClockSettings()
{
  if (RTClock.init() == 0)
  {
    RTClock.getTime((RtcTimeType*)&rtc);
    rtc.seconds = MIN_SECONDS;
    rtc.minutes = MIN_MINUTES;
    rtc.hours = MIN_HOURS;
    rtc.day = MIN_DAY;
    rtc.weekday = MIN_WEEKDAY;
    rtc.month = MIN_MONTH;
    rtc.year = DEF_YEAR;
    RTClock.setTime((RtcTimeType*)&rtc);
  }
}


void dispAlarm()
{
  vfd.clearFrame();
  vfd.print_f_p(ALRM);
  bcdToVFD(binToBcd(alarm.hours), 4 * VFD_BYTES_PER_DIGIT, false, true);
  bcdToVFD(binToBcd(alarm.minutes), 6 * VFD_BYTES_PER_DIGIT, true, false);
  vfd.flipFrame();
}

void dispAlarmState()
{
  vfd.clearFrame();

  if (alarm.is_active) 
    vfd.print_f_p(ALRM_ON);
  else 
    vfd.print_f_p(ALRM_OFF);

  vfd.flipFrame();
}

void dispTime()
{
  vfd.clearFrame();
  bcdToVFD(rtc.hours, 0, false, false);
  bcdToVFD(rtc.minutes, 2 * VFD_BYTES_PER_DIGIT, true, false);
  bcdToVFD(rtc.seconds, 4 * VFD_BYTES_PER_DIGIT, true, false);
  vfd.flipFrame();
}

void dispDate()
{
  vfd.clearFrame();
  uint8_t idx = 0;
  idx = bcdToVFD(rtc.day, idx, false, true);
  idx += VFD_BYTES_PER_DIGIT;
  vfd.write_f(0x20, idx, false);

  uint8_t mon = ((rtc.month >> 4 && 0xF) * 10) + (rtc.month & 0xF);

  idx += VFD_BYTES_PER_DIGIT;
  vfd.write_f(pgm_read_byte(&MONTHS[mon-1][0]), idx, false);
  idx += VFD_BYTES_PER_DIGIT;
  vfd.write_f(pgm_read_byte(&MONTHS[mon-1][1]), idx, false);
  idx += VFD_BYTES_PER_DIGIT;
  vfd.write_f(pgm_read_byte(&MONTHS[mon-1][2]), idx, false);
  idx += VFD_BYTES_PER_DIGIT;
  vfd.write_f(0x20, idx, false);
  vfd.flipFrame();
}

void dispDayOfWeek()
{
  vfd.clearFrame();
  vfd.print_f_p((PGM_P)pgm_read_word(&DAYSOFWEEK[rtc.weekday - 1]));
  vfd.flipFrame();
}

void noDataToVFD()
{
  vfd.setCur(0);
  for (uint8_t i = 0; i < VFD_DIGITS-1; i++) 
    vfd.write(DASH);
  vfd.write(SPACE_CHR);
}

void NoTempToVFD()
{
  vfd.setCur(0);
  vfd.write(DASH);
  vfd.write(DASH);
  vfd.write(DEGREE);
  vfd.write('C');
  vfd.write(SPACE_CHR);
  vfd.write(SPACE_CHR);
  vfd.write(SPACE_CHR);
}

void SaveAlarm()
{
  RTClock.writeBlock((uint8_t*)&alarm, DS1338_USER_AREA, sizeof(alarm));
}

void RestoreAlarm()
{
  RTClock.readBlock((uint8_t*)&alarm, DS1338_USER_AREA, sizeof(alarm));
}

void check4Alarm()
{
  if (alarm.is_active && binToBcd(alarm.hours) == rtc.hours && binToBcd(alarm.minutes) == rtc.minutes && sysState != sysAlarmDisp)
  {
    /*sysState = sysAlarmDisp;
    stateCntr = STD_DISP_TIME * 2;
    vfd.print_f_p(WAKEUP);
    vfd.setFlashAttr(VFD_DIGITS, VFD_FLASH_ALL);
    vfd.flipFrame();*/

    sysState = sysAlarmDisp;
    stateCntr = STD_DISP_TIME * 2;

    alarmedSec = rtc.seconds;
    vfd.spkrOn(10000);
    
    vfd.clearFrame();
    bcdToVFD(rtc.hours, 2 * VFD_BYTES_PER_DIGIT, false, false);
    bcdToVFD(rtc.minutes, 4 * VFD_BYTES_PER_DIGIT, true, false);
    vfd.setFlashAttr(VFD_DIGITS, VFD_FLASH_ALL);
    vfd.flipFrame();    

    //Serial.println(F("Alarm!"));     
  }
}

void IRDecode(decode_results *results) 
{
  Serial.println((long)results->value, HEX);

  if (sysState == sysWaitForSetup)
  {
    sysState = sysRCSetupLeft;
    vfd.print_f_p(RC_LEFT);
    stateCntr = STD_DISP_TIME * 5;
    delay(RCCMD_UPDATE_DELAY);
  }
  else if (sysState == sysRCSetupLeft)
  {
    sysState = sysRCSetupRight;
    vfd.print_f_p(RC_RIGHT);
    stateCntr = STD_DISP_TIME * 5;
    updateRCCmdInFlash(results, &eepromParams.rcAction_Left_Code);
  }
  else if (sysState == sysRCSetupRight)
  {
    sysState = sysRCSetupUp;
    vfd.print_f_p(RC_UP);
    stateCntr = STD_DISP_TIME * 5;
    updateRCCmdInFlash(results, &eepromParams.rcAction_Right_Code);
  }
  else if (sysState == sysRCSetupUp)
  {
    sysState = sysRCSetupDown;
    vfd.print_f_p(RC_DOWN);
    stateCntr = STD_DISP_TIME * 5;
    updateRCCmdInFlash(results, &eepromParams.rcAction_Up_Code);
  }
  else if (sysState == sysRCSetupDown)
  {
    sysState = sysRCSetupSettings;
    vfd.print_f_p(RC_SETTINGS);
    stateCntr = STD_DISP_TIME * 5;
    updateRCCmdInFlash(results, &eepromParams.rcAction_Down_Code);
  }
  else if (sysState == sysRCSetupSettings)
  {
    sysState = sysTimeDisp;
    stateCntr = STD_DISP_TIME;
    vfd.setFlashAttr(VFD_DIGITS, VFD_FLASH_NONE);

    updateRCCmdInFlash(results, &eepromParams.rcAction_Settings_Code);
  }
  else if (sysState == sysTimeDisp || 
    sysState == sysDayOfWeekDisp ||
    sysState == sysExtTempDisp ||
    sysState == sysDateDisp)
  {
    if (isCodeEqual(results, &eepromParams.rcAction_Settings_Code))
    {
      sysState = sysSetAlarmHours;
      stateCntr = STD_DISP_TIME * 5;
      dispAlarm();
      vfd.setFlashAttr(RIGHT_DIGIT_IDX-4, 1);
      vfd.setFlashAttr(RIGHT_DIGIT_IDX-5, 1);      
      
      /*sysState = sysSetHours;
      stateCntr = STD_DISP_TIME * 5;
      if (rtc.year == (uint16_t)-1) defaultClockSettings();
      dispTime();
      vfd.setFlashAttr(RIGHT_DIGIT_IDX, 1);
      vfd.setFlashAttr(RIGHT_DIGIT_IDX-1, 1);*/
    }
  }
  else if (sysState == sysSetAlarmHours)
  {
    stateCntr = STD_DISP_TIME * 5;
    if (isCodeEqual(results, &eepromParams.rcAction_Up_Code))
    {
      uint8_t hours = alarm.hours + 1;
      if (hours > MAX_HOURS) hours = MIN_HOURS;
      alarm.hours = hours;

      SaveAlarm();

  //Serial.print(F("rtc.hour: "));       
  //Serial.println(hours, HEX); 
      
  //Serial.print(F("binToBcd(rtc.hour): "));       
  //Serial.println(binToBcd(hours), HEX); 

      dispAlarm();
      delay(RCCMD_DEBOUNCER);
    }
    else if (isCodeEqual(results, &eepromParams.rcAction_Down_Code))
    {
      uint8_t hours = alarm.hours;
      if (hours > MIN_HOURS) hours--; 
      else hours = MAX_HOURS;
      alarm.hours = hours;

      SaveAlarm();
      
      dispAlarm();
      delay(RCCMD_DEBOUNCER);
    }
    else if (isCodeEqual(results, &eepromParams.rcAction_Right_Code))
    {
      sysState = sysSetAlarmMinutes;
      vfd.setFlashAttr(VFD_DIGITS, VFD_FLASH_NONE);
      vfd.setFlashAttr(RIGHT_DIGIT_IDX-6, 1);
      vfd.setFlashAttr(RIGHT_DIGIT_IDX-7, 1);
      delay(RCCMD_DEBOUNCER);
    }
  }
  else if (sysState == sysSetAlarmMinutes)
  {
    stateCntr = STD_DISP_TIME * 5;
    if (isCodeEqual(results, &eepromParams.rcAction_Up_Code))
    {
      uint8_t minutes = alarm.minutes + 1;
      if (minutes > MAX_MINUTES) minutes = MIN_MINUTES;
      alarm.minutes = minutes;

      SaveAlarm();
      
      dispAlarm();
      delay(RCCMD_DEBOUNCER);
    }
    else if (isCodeEqual(results, &eepromParams.rcAction_Down_Code))
    {
      uint8_t minutes = alarm.minutes;
      if (minutes > MIN_MINUTES) minutes--; 
      else minutes = MAX_MINUTES;
      alarm.minutes = minutes;

      SaveAlarm();
      
      dispAlarm();
      delay(RCCMD_DEBOUNCER);
    }
    else if (isCodeEqual(results, &eepromParams.rcAction_Left_Code))
    {
      sysState = sysSetAlarmHours;
      vfd.setFlashAttr(VFD_DIGITS, VFD_FLASH_NONE);
      vfd.setFlashAttr(RIGHT_DIGIT_IDX-4, 1);
      vfd.setFlashAttr(RIGHT_DIGIT_IDX-5, 1);
      delay(RCCMD_DEBOUNCER);
    }
    else if (isCodeEqual(results, &eepromParams.rcAction_Right_Code))
    {
      /*sysState = sysSetHours;
      stateCntr = STD_DISP_TIME * 5;
      if (rtc.year == (uint16_t)-1) defaultClockSettings();
      dispTime();
      vfd.setFlashAttr(RIGHT_DIGIT_IDX, 1);
      vfd.setFlashAttr(RIGHT_DIGIT_IDX-1, 1);*/

      sysState = sysSetAlarmState;
      stateCntr = STD_DISP_TIME * 5;
      dispAlarmState();
      vfd.setFlashAttr(RIGHT_DIGIT_IDX-5, 1);
      vfd.setFlashAttr(RIGHT_DIGIT_IDX-6, 1);
      vfd.setFlashAttr(RIGHT_DIGIT_IDX-7, 1);      
    }
   
  }
  else if (sysState == sysSetAlarmState)
  {
    stateCntr = STD_DISP_TIME * 5;
    if (isCodeEqual(results, &eepromParams.rcAction_Up_Code) || isCodeEqual(results, &eepromParams.rcAction_Down_Code))
    //if (isCodeEqual(results, &eepromParams.rcAction_Up_Code))
    {
      if (alarm.is_active) alarm.is_active = false;
      else alarm.is_active = true;
      

      SaveAlarm();
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
void loop() {

  while (1)
  {
    {
      switch (sysState)
      {
      case sysSelfTest:
        {
          if (vfd.testStep() == vfd.COMPLETED)
          {
            boot_loader_start();
          }
        }
        break;
      case sysGreetings:
        if (stateCntr == 0)
        {
          sysState = sysWaitForSetup;
          stateCntr = STD_DISP_TIME * 2;
          vfd.print_f_p(RC_SETUP);
          vfd.setFlashAttr(VFD_DIGITS, VFD_FLASH_ALL);
        }
        else
        {
          vfd.setCur(0);
          if (stateCntr > (STD_DISP_TIME / 3 * 2))
            vfd_print_p(HELLO);
          else if (stateCntr > STD_DISP_TIME / 3)
            vfd_print_p(MAGIC);
          else if  (stateCntr > 0)
            vfd_print_p(CLOCK);
        }
        break;
      case sysWaitForSetup:
      case sysRCSetupLeft:
      case sysRCSetupRight:
      case sysRCSetupUp:
      case sysRCSetupDown:
      case sysRCSetupSettings:
      case sysSetHours:
      case sysSetMinutes:
      case sysResetSeconds:
      case sysSetYear:
      case sysSetDayOfWeek:
      case sysSetMonth:
      case sysSetDay:
      case sysSetAlarmHours:
      case sysSetAlarmMinutes:
      case sysSetAlarmState:

        if (stateCntr == 0)
        {
          sysState = sysTimeDisp;
          stateCntr = STD_DISP_TIME;
          vfd.setFlashAttr(VFD_DIGITS, VFD_FLASH_NONE);
        }
        else
        {

          if (sysState == sysSetHours ||
            sysState == sysSetMinutes ||
            sysState == sysResetSeconds)
          {
            dispTime();
          }

          if (mainLoopCntr % 2 == 0)
          {
              vfd.flipFlashState();
              vfd.flipFrame();
          }
        }
        break;

      case sysAlarmDisp:
        {
          if (rtc.hours != binToBcd(alarm.hours) || rtc.minutes != binToBcd(alarm.minutes))
          {
              sysState = sysTimeDisp;
              stateCntr = STD_DISP_TIME;
              vfd.setFlashAttr(VFD_DIGITS, VFD_FLASH_NONE);
              //TODO: disable alarm
          }else
          {
              if (alarmedSec != rtc.seconds)
              {
                vfd.spkrOn(10000);
                alarmedSec = rtc.seconds;
              }
          }

          if (mainLoopCntr % 2 == 0)
          {
             vfd.flipFlashState();
             vfd.flipFrame();
          }
        }
        break;

      case sysTimeDisp:
        {
          if (rtc.year == (uint16_t)-1) noDataToVFD();
          else dispTime();

          if (stateCntr == 0)
          {
            sysState = sysDateDisp;
            stateCntr = STD_DISP_TIME;
          }

          check4Alarm();
        }
        break;

      case sysDayOfWeekDisp:
        if (rtc.year == (uint16_t)-1) noDataToVFD();
        else 
        {
          vfd.setCur(0);
          vfd_print_p((PGM_P)pgm_read_word(&DAYSOFWEEK[rtc.weekday - 1]));
          if (stateCntr == 0)
          {
            sysState = sysExtTempDisp;
            stateCntr = STD_DISP_TIME;
          }
        }
        check4Alarm();
        break;

      case sysExtTempDisp:
        if (temperature == FAILED_TEMPERATURE)NoTempToVFD();
        else 
        {
          vfd.setCur(0);
          if (temperature > 0) vfd.write('+');
          vfd.print((long)temperature, DEC);
          vfd.write(DEGREE);
          vfd.write('C');

          for (uint8_t i = 0; i < VFD_DIGITS-4; i++) 
            vfd.write(SPACE_CHR);
        }
        if (stateCntr == 0)
        {
          sysState = sysTimeDisp;
          stateCntr = STD_DISP_TIME;
        }
        check4Alarm();        
        break;

      case sysIntTempDisp:
        check4Alarm();          
        break;

      case sysDateDisp:
        if (rtc.year == (uint16_t)-1) noDataToVFD();
        else 
        {
          dispDate();
        }
        if (stateCntr == 0)
        {
          sysState = sysDayOfWeekDisp;
          stateCntr = STD_DISP_TIME;
        }
        check4Alarm();                  
        break;

      case sysIntroEffect:

        break;

      case sysStandby:

        break;

      case sysFailure:
        stateCntr = STD_DISP_TIME * 2;
        vfd.print_f_p(FAILURE);
        break;

      default:
        ;       
      }
    }

    //Getting current time
    if (mainLoopCntr % (ONE_SEC_IN_MAIN_LOOPS) == 0)
    {
      if (RTClock.init() == 0)
        RTClock.getTime((RtcTimeType*)&rtc);
    }

    //Getting current temperature
    if (mainLoopCntr % (ONE_SEC_IN_MAIN_LOOPS * 5) == 0)
    {
      if (dsState == dsIdle)
      {
        if ( ds.search(dsAddr)) 
        {
          if (ds.crc8(dsAddr, 7) == dsAddr[7])
          {
            if (dsAddr[0] == 0x28) 
            {
              ds.reset();
              ds.select(dsAddr);
              ds.write(0x44);
              dsState = dsTempConversion;
            }
          }
        }
        else 
        {
          ds.reset_search();
          dsState = dsInitDelay;
        }
      }
      else if (dsState == dsTempConversion)
      {
        ds.reset();
        ds.select(dsAddr);
        ds.write(0xBE);
        for (uint8_t i = 0; i < 9; i++) 
          dsData[i] = ds.read();

        if (ds.crc8(dsData, 8) == dsData[8])
        {
          temperature = getTemperature((uint8_t*)&dsData);
        }
        dsState = dsIdle;
      }
      else if (dsState == dsInitDelay)
      {
        dsState = dsIdle;
      }

      if (temperature != FAILED_TEMPERATURE)
      {
        if (temperature > 0) Serial.write('+');
        else if (temperature < 0) Serial.write('-');
        Serial.print((long)temperature, DEC);
        Serial.write('C');
      }
      Serial.println();

      Serial.print("Photocell: ");
      Serial.println((long)vfd.getLightSensorVal(), DEC);
    }

    //Handling RC commands
    decode_results* ir_res = vfd.getIR_RC_Code();
    if (ir_res != NULL) 
    {
      cli();
      actModeTimer = SECONDS_IN_ACTIVE_MODE;
      sei();

      if (sysState == sysStandby)
      {
        switchVFD(sysTimeDisp);
      }
      //shortBeep();
      IRDecode(ir_res);
    }

    if (actModeTimer == 0 &&  sysState != sysStandby)
    {
      uint8_t brightness = VFD_DIMMING_MAX;
      while (brightness != 0)
      {            
        vfd.displayOnCmd(brightness--);
        delay(500);
      }
      toStandBy();
    }

    if (pirEvent)
    {
      cli();
      pirEvent = false;
      actModeTimer = SECONDS_IN_ACTIVE_MODE;
      sei();

      if (sysState == sysStandby)
      {
        switchVFD(sysTimeDisp);
      }
    }

    //if (sysState == sysGreetings)
    //  longBeepAsync();

    //sleep_mode();
    delay(MAIN_LOOP_DELAY);

    if (sysState != sysStandby)
    {
        pulseLEDs();
    }

    mainLoopCntr++;
    if (mainLoopCntr % ONE_SEC_IN_MAIN_LOOPS == 0)
    {
      //1 Hz
      if (stateCntr != 0) stateCntr--; 
      if (actModeTimer != 0) actModeTimer--;
    }
  }
}

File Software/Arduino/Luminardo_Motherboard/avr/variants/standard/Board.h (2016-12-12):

#ifndef Board_h
#define Board_h

#if (LUMINARDO_REV) && (LUMINARDO_REV >= 2)
    #define RTC_INT_PIN		1	//PB1
    #define VFD_SPRK_PIN	3	//PB3
#else
    #define VFD_SPRK_PIN    	13 	//PD5
    #define RTC_INT_PIN		3	//PB3
#endif

#define TEMP_SNSR_PIN 		24	//PA0
#define VFD_CS_PIN   		29 	//PA5
#define VFD_SCLK_PIN 		28 	//PA4
#define VFD_DATAI_PIN 		19 	//PC3
#define VFD_DATAO_PIN 		20 	//PC4
#define VFD_SHDN_PIN    	26 	//PA2
#define VFD_R_PIN       	15 	//PD7
#define VFD_G_PIN       	14 	//PD6
#define VFD_B_PIN       	12 	//PD4

#define VFD_PWR_EN_PIN      	27 	//PA3
#define VFD_LIGHT_SNR_PIN    	31	//PA7
#define VFD_IR_REC_PIN		25	//PA1
#define SPI_SS2_PIN		30	//PA6
#define SPI_SCK_PIN		7	//PB7
#define SPI_MISO_PIN		6	//PB6
#define SPI_MOSI_PIN		5	//PB5
#define SPI_SS_PIN		4	//PB4

#define PIR_PIN			2	//PB2
#define MAX_INT_PIN		18	//PC2

#define FAILED_TEMPERATURE -999

enum enum_DsState
{
    dsIdle,
    dsTempConversion,
    dsInitDelay
};

#endif

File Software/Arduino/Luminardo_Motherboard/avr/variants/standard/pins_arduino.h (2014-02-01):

#ifndef Pins_Arduino_h
#define Pins_Arduino_h

#include <avr/pgmspace.h>

// ATMEL ATMEGA1284P
//
//                   +---\/---+
//           (D 0) PB0  1|        |40  PA0 (AI 0 / D24)
//           (D 1) PB1  2|        |39  PA1 (AI 1 / D25)
//      INT2 (D 2) PB2  3|        |38  PA2 (AI 2 / D26)
//       PWM (D 3) PB3  4|        |37  PA3 (AI 3 / D27)
//    PWM/SS (D 4) PB4  5|        |36  PA4 (AI 4 / D28)
//      MOSI (D 5) PB5  6|        |35  PA5 (AI 5 / D29)
//  PWM/MISO (D 6) PB6  7|        |34  PA6 (AI 6 / D30)
//   PWM/SCK (D 7) PB7  8|        |33  PA7 (AI 7 / D31)
//                 RST  9|        |32  AREF
//                 VCC 10|        |31  GND 
//                 GND 11|        |30  AVCC
//               XTAL2 12|        |29  PC7 (D 23)
//               XTAL1 13|        |28  PC6 (D 22)
//      RX0 (D 8)  PD0 14|        |27  PC5 (D 21) TDI
//      TX0 (D 9)  PD1 15|        |26  PC4 (D 20) TDO
// RX1/INT0 (D 10) PD2 16|        |25  PC3 (D 19) TMS
// TX1/INT1 (D 11) PD3 17|        |24  PC2 (D 18) TCK
//      PWM (D 12) PD4 18|        |23  PC1 (D 17) SDA
//      PWM (D 13) PD5 19|        |22  PC0 (D 16) SCL
//      PWM (D 14) PD6 20|        |21  PD7 (D 15) PWM
//                   +--------+
//

/*
   PCINT15-8: D7-0  : bit 1
   PCINT31-24: D15-8  : bit 3
   PCINT23-16: D23-16 : bit 2
   PCINT7-0: D31-24   : bit 0
   */

#define NUM_DIGITAL_PINS            31
#define NUM_ANALOG_INPUTS           8
#define analogInputToDigitalPin(p)  ((p < NUM_ANALOG_INPUTS) ? (p) + 24 : -1)

#define digitalPinHasPWM(p)         ((p) == 3 || (p) == 4 || (p) == 6 || (p) == 7 || (p) == 12 || (p) == 13 || (p) == 14 || (p) == 15)

static const uint8_t SS   = 4;
static const uint8_t MOSI = 5;
static const uint8_t MISO = 6;
static const uint8_t SCK  = 7;

static const uint8_t SDA = 17;
static const uint8_t SCL = 16;
static const uint8_t LED = 7;

static const uint8_t A0 = 24;
static const uint8_t A1 = 25;
static const uint8_t A2 = 26;
static const uint8_t A3 = 27;
static const uint8_t A4 = 28;
static const uint8_t A5 = 29;
static const uint8_t A6 = 30;
static const uint8_t A7 = 31;

#define digitalPinToPCICR(p)    (((p) >= 0 && (p) < NUM_DIGITAL_PINS) ? (&PCICR) : ((uint8_t *)0))
#define digitalPinToPCICRbit(p) (((p) <= 7) ? 1 : (((p) <= 15) ? 3 : (((p) <= 23) ? 2 : 0)))
#define digitalPinToPCMSK(p)    (((p) <= 7) ? (&PCMSK2) : (((p) <= 13) ? (&PCMSK0) : (((p) <= 21) ? (&PCMSK1) : ((uint8_t *)0))))
#define digitalPinToPCMSKbit(p) ((p) % 8)

#ifdef ARDUINO_MAIN

#define PA 1
#define PB 2
#define PC 3
#define PD 4

// these arrays map port names (e.g. port B) to the
// appropriate addresses for various functions (e.g. reading
// and writing)
const uint16_t PROGMEM port_to_mode_PGM[] =
{
	NOT_A_PORT,
	(uint16_t) &DDRA,
	(uint16_t) &DDRB,
	(uint16_t) &DDRC,
	(uint16_t) &DDRD,
};

const uint16_t PROGMEM port_to_output_PGM[] =
{
	NOT_A_PORT,
	(uint16_t) &PORTA,
	(uint16_t) &PORTB,
	(uint16_t) &PORTC,
	(uint16_t) &PORTD,
};

const uint16_t PROGMEM port_to_input_PGM[] =
{
	NOT_A_PORT,
	(uint16_t) &PINA,
	(uint16_t) &PINB,
	(uint16_t) &PINC,
	(uint16_t) &PIND,
};

const uint8_t PROGMEM digital_pin_to_port_PGM[] =
{
	PB, /* 0 */
	PB,
	PB,
	PB,
	PB,
	PB,
	PB,
	PB,
	PD, /* 8 */
	PD,
	PD,
	PD,
	PD,
	PD,
	PD,
	PD,
	PC, /* 16 */
	PC,
	PC,
	PC,
	PC,
	PC,
   	PC,
	PC,
	PA, /* 24 */
	PA,
	PA,
	PA,
	PA,
	PA,
	PA,
	PA  /* 31 */
};

const uint8_t PROGMEM digital_pin_to_bit_mask_PGM[] =
{
	_BV(0), /* 0, port B */
	_BV(1),
	_BV(2),
	_BV(3),
	_BV(4),
	_BV(5),
	_BV(6),
	_BV(7),
	_BV(0), /* 8, port D */
	_BV(1),
	_BV(2),
	_BV(3),
	_BV(4),
	_BV(5),
	_BV(6),
	_BV(7),
	_BV(0), /* 16, port C */
	_BV(1),
	_BV(2),
	_BV(3),
	_BV(4),
	_BV(5),
	_BV(6),
	_BV(7),
	_BV(0), /* 24, port A */
	_BV(1),
	_BV(2),
	_BV(3),
	_BV(4),
	_BV(5),
	_BV(6),
	_BV(7)
};

const uint8_t PROGMEM digital_pin_to_timer_PGM[] =
{
	NOT_ON_TIMER, 	/* 0  - PB0 */
	NOT_ON_TIMER, 	/* 1  - PB1 */
	NOT_ON_TIMER, 	/* 2  - PB2 */
	TIMER0A,     	/* 3  - PB3 */
	TIMER0B, 	/* 4  - PB4 */
	NOT_ON_TIMER, 	/* 5  - PB5 */
	TIMER3A, 	/* 6  - PB6 */
	TIMER3B,	/* 7  - PB7 */
	NOT_ON_TIMER, 	/* 8  - PD0 */
	NOT_ON_TIMER, 	/* 9  - PD1 */
	NOT_ON_TIMER, 	/* 10 - PD2 */
	NOT_ON_TIMER, 	/* 11 - PD3 */
	TIMER1B,     	/* 12 - PD4 */
	TIMER1A,     	/* 13 - PD5 */
	TIMER2B,     	/* 14 - PD6 */
	TIMER2A,     	/* 15 - PD7 */
	NOT_ON_TIMER, 	/* 16 - PC0 */
	NOT_ON_TIMER,   /* 17 - PC1 */
	NOT_ON_TIMER,   /* 18 - PC2 */
	NOT_ON_TIMER,   /* 19 - PC3 */
	NOT_ON_TIMER,   /* 20 - PC4 */
	NOT_ON_TIMER,   /* 21 - PC5 */
	NOT_ON_TIMER,   /* 22 - PC6 */
	NOT_ON_TIMER,   /* 23 - PC7 */
	NOT_ON_TIMER,   /* 24 - PA0 */
	NOT_ON_TIMER,   /* 25 - PA1 */
	NOT_ON_TIMER,   /* 26 - PA2 */
	NOT_ON_TIMER,   /* 27 - PA3 */
	NOT_ON_TIMER,   /* 28 - PA4 */
	NOT_ON_TIMER,   /* 29 - PA5 */
	NOT_ON_TIMER,   /* 30 - PA6 */
	NOT_ON_TIMER   /* 31 - PA7 */
};

#endif // ARDUINO_MAIN

#endif // Pins_Arduino_h
// vim:ai:cin:sts=2 sw=2 ft=cpp

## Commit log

2014-02-01 Initial commit
    Luminardo Rev 1.0
    [FluoroDuino.brd, FluoroDuino.sch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]
2014-02-01 Design files for MVFD panel and Backpack
    Design files for MVFD panel and serial backpack Rev.1.0
    [MVFDPanel_16S8D.brd, MVFDPanel_16S8D.sch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]
2014-03-23 #define LUMINARDO
    #define LUMINARDO is appended to Arduino.h
2016-06-25 Compatible with Arduino 1.6.9
    Restructuring to make it compatible with Arduino 1.6.9 IDE

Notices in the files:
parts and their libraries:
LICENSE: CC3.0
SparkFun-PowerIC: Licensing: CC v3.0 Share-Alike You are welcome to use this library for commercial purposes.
